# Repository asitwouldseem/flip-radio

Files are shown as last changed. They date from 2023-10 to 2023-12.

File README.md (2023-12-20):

# flip-radio
A project to convert an old Philips RS-100 clock radio into a modern smart speaker.

Ahhh yes... this project. I'll admit I originally didn't set out to convert a 1970's vintage clock radio into a streaming speaker... but one late night browse on everyone's favourite online marketplace opened the rabbithole I was about to fall down for the next few months. 

I was planning to use the [Squeezelite-ESP32](https://github.com/sle118/squeezelite-esp32) firmware as the core of my tinkering, but soon realised that I needed something a little more friendlier to bodging. I had a Pi Zero W hooked up to my home network running as a DVB server which struggled keeping up with some of the HD stations. I eventually decided to rotate through my stock of single-board computers and put it to use here. Be prepared. This is my first time programming in Python, let alone asynchronous Python. Be warned. She be very rough.

This project makes use of the [PySqueezebox](https://github.com/rajlaud/pysqueezebox) library to communicate with LMS. If you are adapting my work (which you're free to do), I highly recommend using LMS for multi-room audio. I'm yet to find something to replace it (yes, even Roon). It's very 2000s out of the box, but I'm constantly surprised by what I've been able to throw it. DSD256 files? Yep. DVB radio? Yep. Streaming analogue sources to other devices? YES!

## Build
Oooh boy. This clock was filthy... Before I did anything else, I pulled it apart[^1] and left the cream-coloured plastic out to retrobright in Brisbane's unescapable sunshine. Fellow makers - a warning that Orange Power is great for cleaning muck. But it will also  melt lettering off a large grocery chain's plastic bags with ease. Sigh! Talk about making it harder for myself.

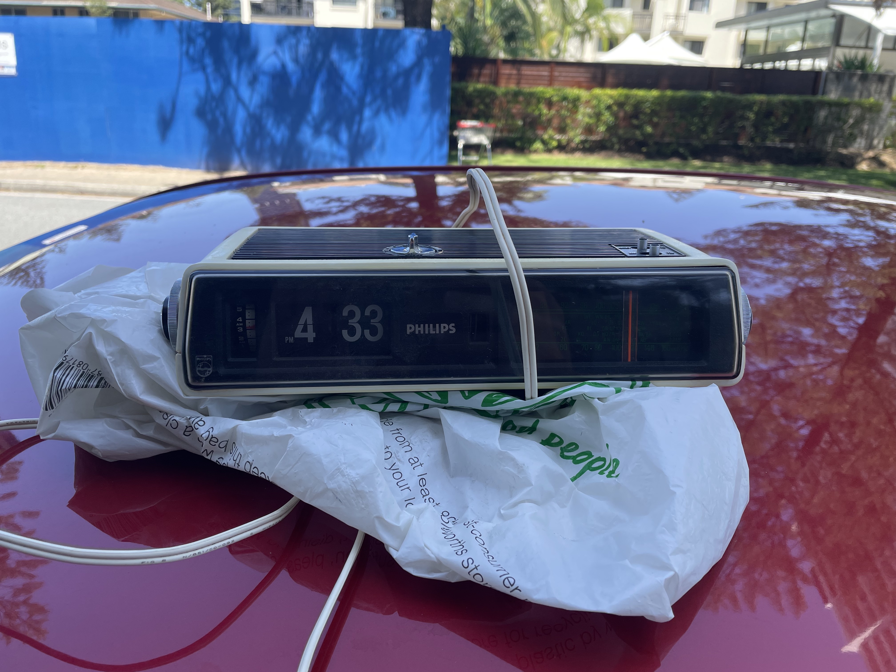
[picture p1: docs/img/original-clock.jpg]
Dirty flip clock sitting atop red car Picking up the clock


At this point in the process, I knew the clock didn't flip - but not why it was stubborn to flip. A deep dive into the forums revealed that it's often the AC motors which fail which was certainly the case with this particular clock. Great. Where am I meant to find a replacement motor in 2023?!

I have to make a massive shout out to @dpwe's [StepperFlipClock](https://github.com/dpwe/StepperFlipClock) repository which helped in replacing the failed Copal motor with a 28BYJ-48 stepper motor. I found myself deep in horopalettology forums and found a very active community of hobbyists keeping these old clocks going. A quick trip to my local Jaycar and I had both a stepper motor and real-time clock to hand. Huzzah!

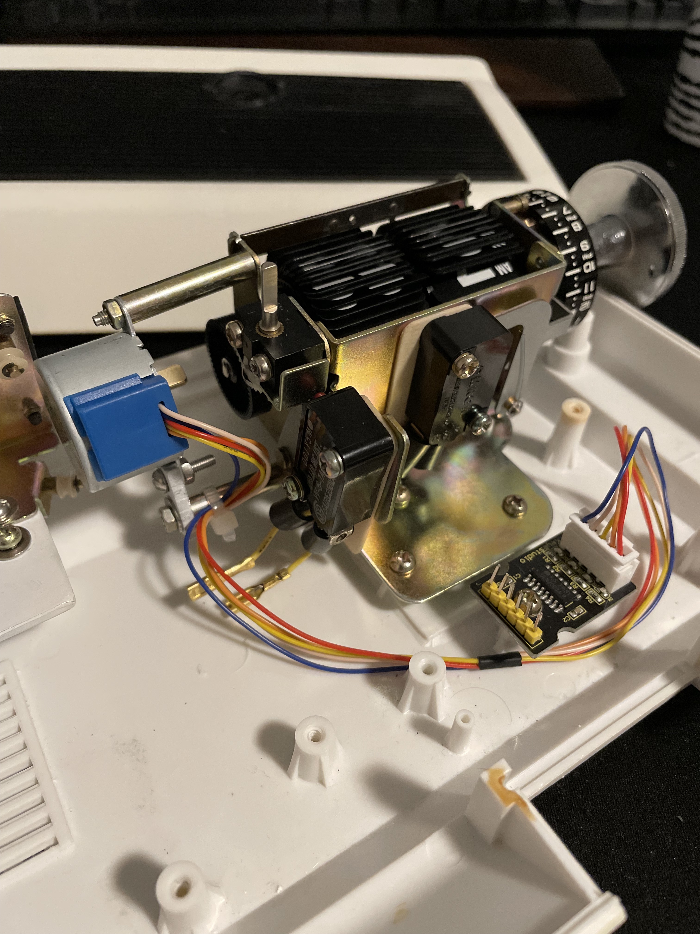
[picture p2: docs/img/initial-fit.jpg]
Split flap mechanism in clock body Initial clock mechanism fit


A quick test fit discovered another common problem with these mechanisms - the hour split-flap was just a little optimistic at the top of the hour. This is by far the most fiddly work I've done to date so I didn't think to photograph it. There are plenty of great [YouTube tutorials](https://www.youtube.com/watch?v=wzLPRFDi2xg) on how to fix this particular issue.

More to follow soon.
...
...

[^1]: I am comfortable working on low voltages but not high voltages. This project is low voltage by design. Opening old electronics comes with some risk and care required to discharge things appropriately. Don't be stupid. If you're working on high voltages, please. Call an electrician.

## Bill of Materials
- 1x Philips RS-100 Clock Radio
- 1x Raspberry Pi Zero WH (A$25)
- 1x DS3231 Real Time Clock Module (A$20)
- 1x 28BYJ-48 Stepper Motor + ULN2003 Driver (A$10)
- 1x Adafruit MAX98357 I<sup>2</sup>S Amplifier (A$10)
- 1x ER-OLEDM028-1W SPI OLED Display (US$30)
- 1x 'warm white' LED (A$0.07)
- 1x 330ohm resistor (A$0.10)
- 9x 1k resistor (A$2.70)
- 9x 10k resistor (A$2.70)
- 3x 2 wire screw terminal (A$3.90)
- 1x 3 wire screw terminal (A$2.50)
- 2x 1/4 size soldered breadboard (A$5)
- 2x EC11 rotary encoder (A$4.25)
- 1x 75mm 8ohm speaker (A$7.50)
- 1x barrel jack panel mount (A$6.75)

## Max Power Consumption
- Raspberry Pi Zero WH (5V, 1.2A)
- 28BYJ-48 Stepper Motor (5V, 240mA)
- Adafruit MAX98357 (2.5-5V, 650mA)
- SPI OLED Display (3-5V, 55mA)
- LED (2.7V, 20mA)
- DS3231 (3.3V, < 300µA)

Napkin maths... eh? 2.5A 'ought to be enough.

### Generative AI
Because I was building this at the same time as a [silly gift](https://github.com/asitwouldseem/groundhog-day/) some of the stepper motor code was partly produced by Generative AI. I had to adapt it for the Pi rather than Pico, but full disclosure nonetheless.

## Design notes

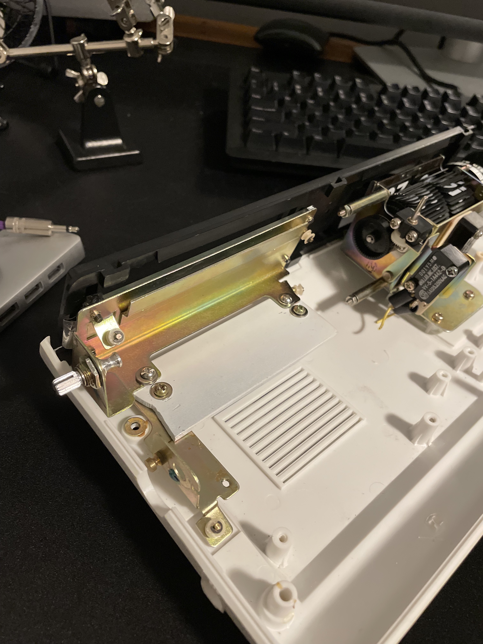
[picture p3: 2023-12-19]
docs/img/custom-bracket.jpg

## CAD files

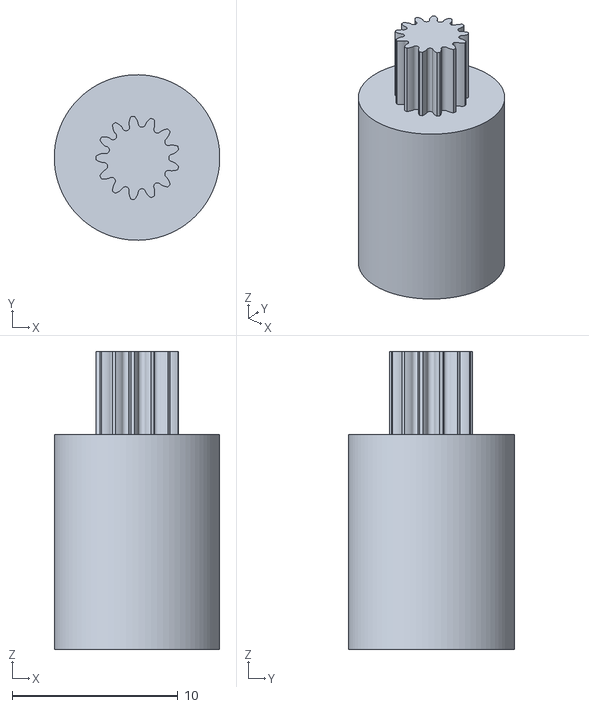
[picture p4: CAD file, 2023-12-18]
docs/pinion-replacement.stl
10.00 x 10.00 x 18.0

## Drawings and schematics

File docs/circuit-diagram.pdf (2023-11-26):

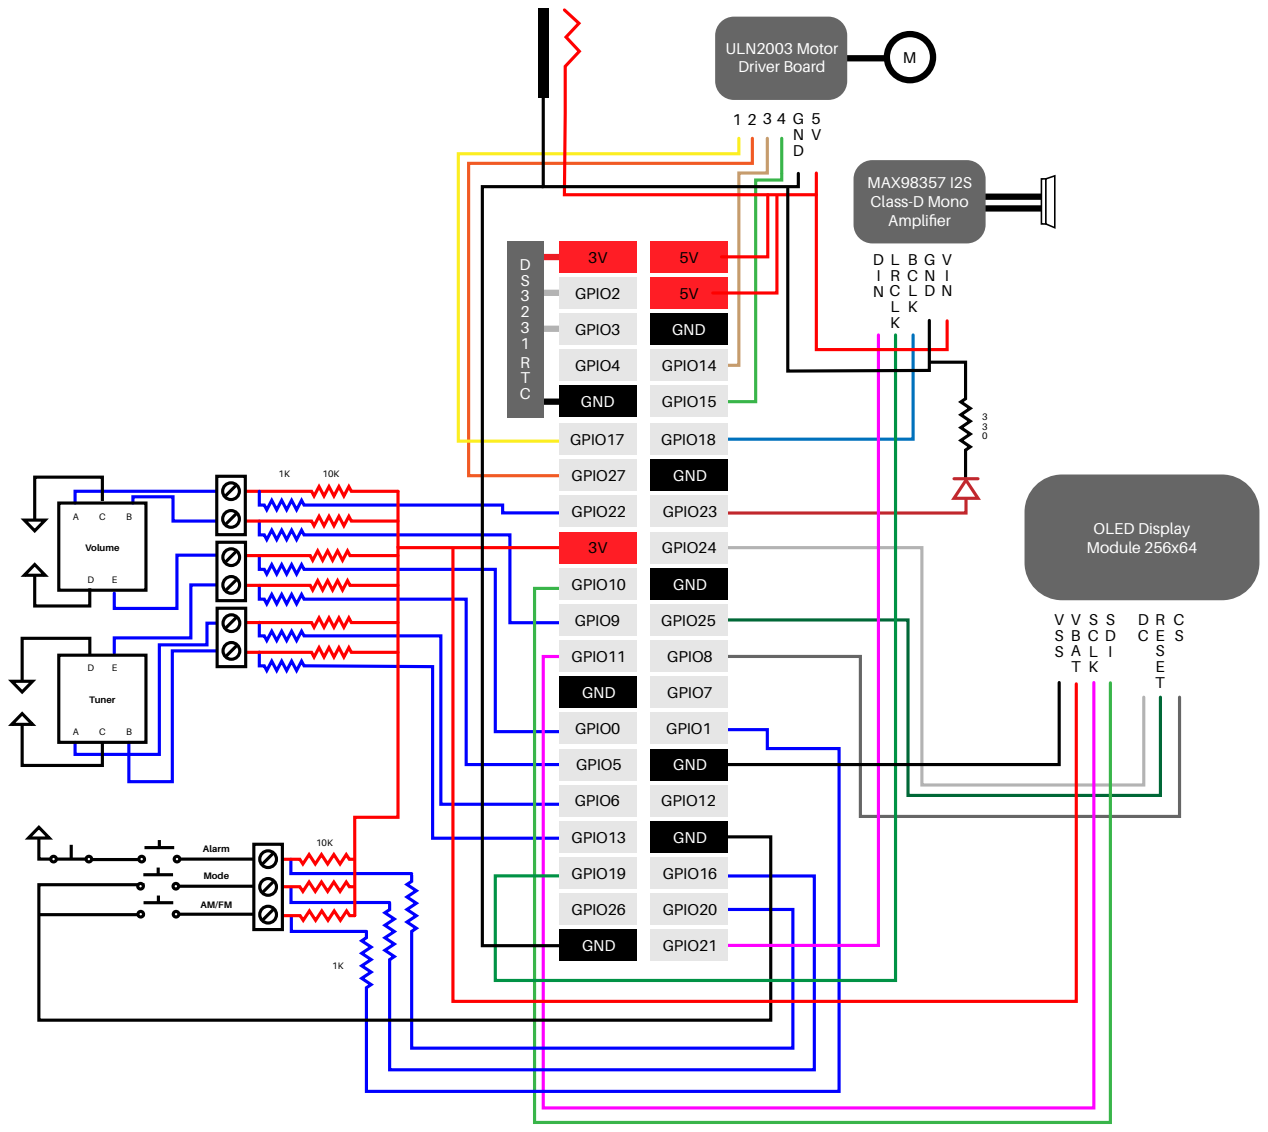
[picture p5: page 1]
DS3231RTC; MAX98357 I2S Class-D Mono Amplifier; ULN2003 Motor Driver Board; GPIO2; GPIO3; GPIO4; GND; GPIO17; GPIO27; GPIO22; GPIO10; GPIO11; GPIO0; GPIO5; GPIO6; GPIO13; GPIO19; GPIO26; GPIO14; GPIO15; GPIO18; GPIO23; GPIO24; GPIO25; GPIO8; GPIO7; GPIO1; GPIO12; GPIO16; GPIO20; GPIO21; DIN; LRCLK; BCLK; VIN; OLED Display Module 256x64; Alarm; Mode; GPIO9; Volume; Tuner; VSS; VBAT; SCLK; SDI; RESET

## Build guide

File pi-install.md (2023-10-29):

# Getting Started
## Components
- Audio: [Adafruit MAX98357 I<sup>2</sup>S DAC/Amp](https://www.adafruit.com/product/3006)
- RTC: [DS3231 Real Time Clock](https://www.jaycar.com.au/rtc-clock-module-for-raspberry-pi/p/XC9044)

## Hardware
### I<sup>2</sup>S DAC/Amp
Follow the Adafruit instructions for now. I'll update later :) 

Be sure to decline the script that runs a blank audio stream as it doesn't allow Squeezelite to access the card directly.

### Real Time Clock
I use a Jaycar-special DS3231 RTC module. There wasn't much documentation out there, but it connects to pins 1,3,5,7 and 9. A real-time clock is possibly overkill given internet-connected and a flip clock. But let's do it anyway.

Install our dependencies:
```
sudo apt-get update
sudo apt-get install python-smbus
sudo apt-get install i2c-tools
```

We should have enabled I2C kernel support previously, but just in case. Go into raspi-config is enable it.

We'll now edit the modules file to add support for the RTC.
```
sudo nano /etc/modules

i2c-bcm2708
i2c-dev
rtc-ds1307
```

Check whether the DS3231 is detected. You should get a 'UU' in row 60, column 8.
```
sudo i2cdetect -y 1
```

Load the clock at boot. 
```
sudo nano /etc/rc.local
```

Add the following lines before exit 0
```
echo ds1307 0x68 > /sys/class/i2c-adapter/i2c-1/new_device
hwclock -s
```

## Squeezelite
I'm a big fan of the Logitech Media Server project for multi-room streaming. I know I probably should use a more up-to-date binary, but #lazy. 

Install Squeezelite.
```
sudo apt-get install squeezelite
```

Check to see if the Adafruit DAC is visible to Squeezelite. This command should list all your audio outputs on the Pi. For me, it's `hw:CARD=sndrpihifiberry,DEV=0`. Generally you want to select hw cards over the others.
```
squeezelite -l
```

We'll now modify the service specific to (y)our own streaming setup. The Pi Zero can't handle DSF so we're not going to mess with this. The below configuration works well for my particular setup.
```
[Unit]
Description=Squeezelite headless streaming music client

After=network.target

[Service]
ExecStart=/usr/bin/squeezelite -o hw:CARD=sndrpihifiberry,DEV=0 -s 10.0.1.100 -n Radio -a 120:4::0                

[Install]
WantedBy=multi-user.target
```

Enable Squeezelite from boot.
```
sudo systemctl enable squeezelite.service
```

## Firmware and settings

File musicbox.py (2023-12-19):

#!/usr/bin/python3
from PIL import ImageFont
from pysqueezebox import Server
import RPi.GPIO as GPIO
import aiohttp
import asyncio
import time

# OLED display
from luma.core.interface.serial import spi
from luma.core.render import canvas
from luma.oled.device import ssd1322

# Define input pins
BUTTON_VOL = 13
BUTTON_TUNER = 0
VOL_CLK = 6
VOL_DT = 22
TUNER_CLK = 5
TUNER_DT = 9
CLOCK_LED = 23

# Define LMS settings
LMS_SERVER = '10.0.1.100'
PLAYER_NAME = 'Radio'

# OLED display
serial = spi(device=0, port=0)
device = ssd1322(serial)

padding = 5
top = 0 + padding
left = 0 + padding
bottom = device.size[1] - padding
right = device.size[0] - padding
middle = device.size[1] / 2

font_title = ImageFont.truetype('/home/cameron/fonts/WorkSans-SemiBold.ttf', 14)
font_artist = ImageFont.truetype('/home/cameron/fonts/WorkSans-Light.ttf', 12)
font_info = ImageFont.truetype('/home/cameron/fonts/WorkSans-Light.ttf', 12)

# Rotary encoders
vol_counter = 0
vol_change = 5
volClkLast = None
tunerClkLast = None

# Case I/O
def pause(channel):
    loop.run_in_executor(None, lambda: asyncio.run(pauseTrack()))

def tuner(channel):
    loop.run_in_executor(None, lambda: asyncio.run(powerDevice()))

def volume_encoder(channel):
    global vol_counter, volClkLast

    volClk = GPIO.input(VOL_CLK)
    volDt = GPIO.input(VOL_DT)

    if volClkLast is not None:
        if volClk != volClkLast:
            if volDt != volClk:
                vol_counter = vol_change
            else:
                vol_counter = -vol_change
        else:
            vol_counter = 0
    
    volClkLast = volClk

    # Pass encoder value to setVolume to work out the change.
    loop.call_later(0.5, lambda: asyncio.create_task(setVolume(vol_counter)))

def tuner_encoder(channel):
    global tuner_counter, tunerClkLast

    tunerClk = GPIO.input(TUNER_CLK)
    tunerDt = GPIO.input(TUNER_DT)

    #TODO: Add rotary encoder to control... something.

def clear_display():
    device.clear()

# We call this function to update the OLED with track information.
async def nowPlaying():
    last_title = None

    async with aiohttp.ClientSession() as session:
        lms = Server(session, LMS_SERVER)
        player = await lms.async_get_player(name=PLAYER_NAME)
        await player.async_update()

        # We'll only update when the track changes.
        if player.title != last_title:
            if player.title:
                with canvas(device) as draw:
                    draw.text((left, middle), player.title, font=font_title, anchor="ls", fill="white")
                    draw.text((left, middle + 15), player.artist, font=font_artist, anchor="ls", fill="white")
            else:
                with canvas(device) as draw:
                    draw.text((left, middle), "No track information.", anchor="ls", font=font_info, fill="white")

        # This shouldn't get called... but just in case LMS is doing something odd.
        else:
            clear_display()

        last_title = player.title

# Interactions with Logitech Media Server
async def powerDevice():
    async with aiohttp.ClientSession() as session:
        lms = Server(session, LMS_SERVER)
        player = await lms.async_get_player(name=PLAYER_NAME)
        await player.async_update()

        if player.power == 1: 
            await player.async_set_power(0)
        else:
            await player.async_set_power(1)

            # This makes sure the Now Playing display reappears after a manual power off.
            loop.run_in_executor(None, lambda: asyncio.run(nowPlaying()))

async def pauseTrack():
    async with aiohttp.ClientSession() as session:
        lms = Server(session, LMS_SERVER)
        player = await lms.async_get_player(name=PLAYER_NAME)
        await player.async_toggle_pause()

async def setVolume(encoder_value):
    async with aiohttp.ClientSession() as session:
        lms = Server(session, LMS_SERVER)
        player = await lms.async_get_player(name=PLAYER_NAME)
        await player.async_update()

        # Add encoder value to volume.
        new_volume = player.volume + encoder_value
        new_volume = max(0, min(new_volume, 100))

        # Send to LMS.
        await player.async_set_volume(new_volume)

        # Display on OLED.
        with canvas(device) as draw:
            draw.text((left, middle), "Volume: " + str(new_volume), anchor="ls", font=font_info, fill="white")

async def setup():
    async with aiohttp.ClientSession() as session:
        lms = Server(session, LMS_SERVER)
        player = await lms.async_get_player(name=PLAYER_NAME)

        with canvas(device) as draw:
          draw.text((left, middle), "Connection established.", font=font_info, anchor="ls", fill="white")

        # If we're not playing anything, it'll show this forever. Lame.
        time.sleep(5)
        clear_display()

async def main():
    while True:
        async with aiohttp.ClientSession() as session:
            lms = Server(session, LMS_SERVER)
            player = await lms.async_get_player(name=PLAYER_NAME)
            await player.async_update()

            if player.mode == 'play':
                GPIO.output(CLOCK_LED,GPIO.HIGH)
                loop.run_in_executor(None, lambda: asyncio.run(nowPlaying()))

            # If we've stopped playback. Put away the fancy stuff.
            if player.mode == 'stop':
                GPIO.output(CLOCK_LED,GPIO.LOW)
                clear_display()

            await asyncio.sleep(1)

if __name__ == '__main__':
    try:
        # Create and run the event loop for setup
        loop = asyncio.new_event_loop()
        asyncio.set_event_loop(loop)        
        loop.run_until_complete(setup())

        # Setup GPIO
        GPIO.setmode(GPIO.BCM)
        GPIO.setup(CLOCK_LED, GPIO.OUT)
        GPIO.setup(BUTTON_VOL, GPIO.IN)
        GPIO.setup(BUTTON_TUNER, GPIO.IN)
        GPIO.setup(VOL_CLK, GPIO.IN)
        GPIO.setup(VOL_DT, GPIO.IN)
        GPIO.setup(TUNER_CLK, GPIO.IN)
        GPIO.setup(TUNER_DT, GPIO.IN)

        # Rotary encoders
        volClkLast = GPIO.input(VOL_CLK)

        # Event listeners
        GPIO.add_event_detect(BUTTON_VOL, GPIO.RISING, callback=pause, bouncetime=500)
        GPIO.add_event_detect(BUTTON_TUNER, GPIO.RISING, callback=tuner, bouncetime=500)
        GPIO.add_event_detect(VOL_CLK, GPIO.BOTH, callback=volume_encoder, bouncetime=225)
        GPIO.add_event_detect(TUNER_CLK, GPIO.BOTH, callback=tuner_encoder, bouncetime=225)

        # Run the main loop
        loop.run_until_complete(main())

    except KeyboardInterrupt:
        pass
    except Exception as e:
        print(f"Error: {e}")
    finally:
        clear_display()
        GPIO.cleanup()

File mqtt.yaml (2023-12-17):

mqtt:
  host: #.#.#.#
  port: 1883
  user: ""
  password: ""
  topic_prefix: flip_radio
  ha_discovery:
    enabled: yes

gpio_modules:
  - name: rpi
    module: raspberrypi

digital_inputs:
  - name: mode
    module: rpi
    pin: 1
    on_payload: "Auto"
    off_payload: "Manual"
  - name: tuner
    module: rpi
    pin: 16
    on_payload: "FM"
    off_payload: "AM"
  - name: alarm
    module: rpi
    pin: 20
    inverted: yes

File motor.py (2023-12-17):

#!/usr/bin/python3
import RPi.GPIO as GPIO
import time

# 28BYJ-48 Pins
IN1 = 17
IN2 = 27
IN3 = 14
IN4 = 15

# Adjust to match the Copal mechanism
STEPS_PER_MINUTE = 40

pins = [IN1, IN2, IN3, IN4]
sequence = [1, 0, 0, 0], [0, 1, 0, 0], [0, 0, 1, 0], [0, 0, 0, 1]

GPIO.setmode(GPIO.BCM)
GPIO.setup(pins, GPIO.OUT)

def move_motor(steps):
    for _ in range(steps):
        for step in sequence:
            for i in range(len(pins)):
                GPIO.output(pins[i], step[i])
                time.sleep(0.001)

def clock():
    current_time = time.localtime(time.time())

    if current_time.tm_sec == 0:
        move_motor(STEPS_PER_MINUTE)
        print("Moved the clocks forward.")

if __name__ == '__main__':
    try:
        while True:
            clock()
            time.sleep(1)

    except KeyboardInterrupt:
        pass
    except Exception as e:
        print(f"Error: {e}")
    finally:
        GPIO.cleanup()

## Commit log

2023-11-08 Add diagram, update bill of materials
2023-11-19 Add MQTT_IO, update bill of materials
2023-11-22 Remove second rotary encoder
2023-12-04 Add working transport control, start programming encoders
2023-12-17 Remove LED from MQTT
2023-12-17 Add second encoder button for power control
2023-12-18 Create services dir, add stl
    [pinion-replacement.stl]
2023-12-19 Add nowplaying() function, check current volume before changing.
